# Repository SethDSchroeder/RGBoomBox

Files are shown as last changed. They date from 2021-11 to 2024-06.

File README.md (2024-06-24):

# RGBoomBox

The RGBBoomBox is a bluetooth speaker with BLINKENLIGHTS

**6/24 update** I'm reworking and completing this project now based around an Arduino MEGA board. Ideally, the first iteration will be designed as a shield for the mega which the daughter components plug into. After that, it will be revamped into a single board. All further updates to this project will be in the MEGA branch until it is semi-functional then I will merge it back into main.

**List of components used:**

* Bluetooth audio board: https://www.amazon.com/gp/product/B07W4PJ469/ref=ppx_yo_dt_b_search_asin_title?ie=UTF8&psc=1
* Audio amplifier: https://www.adafruit.com/product/1752
* RGB Matrix: https://www.adafruit.com/product/420
* Rotary encoder for volume: https://www.sparkfun.com/products/15141 and https://www.sparkfun.com/products/10597
* Matrix shield: https://www.adafruit.com/product/2601

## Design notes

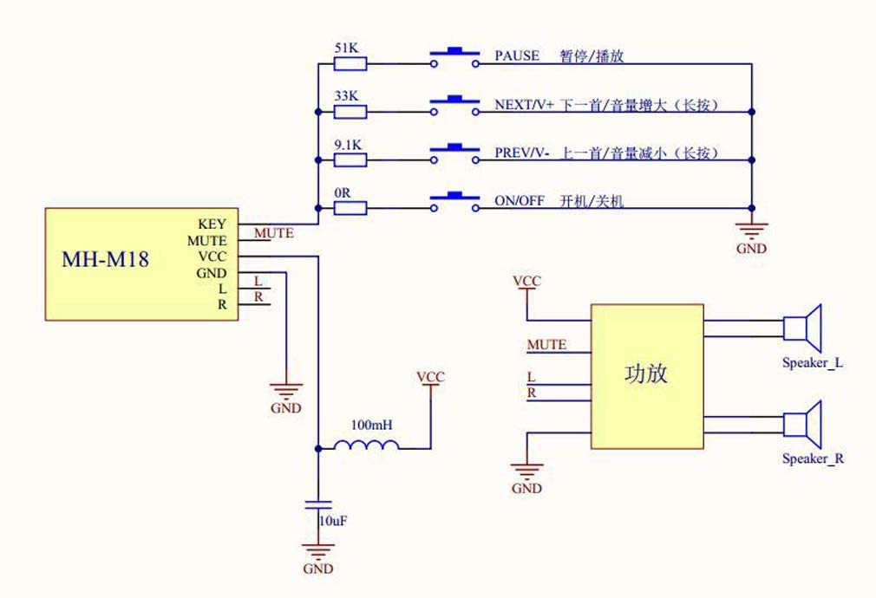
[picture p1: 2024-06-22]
bluetooth-board-layout.jpg

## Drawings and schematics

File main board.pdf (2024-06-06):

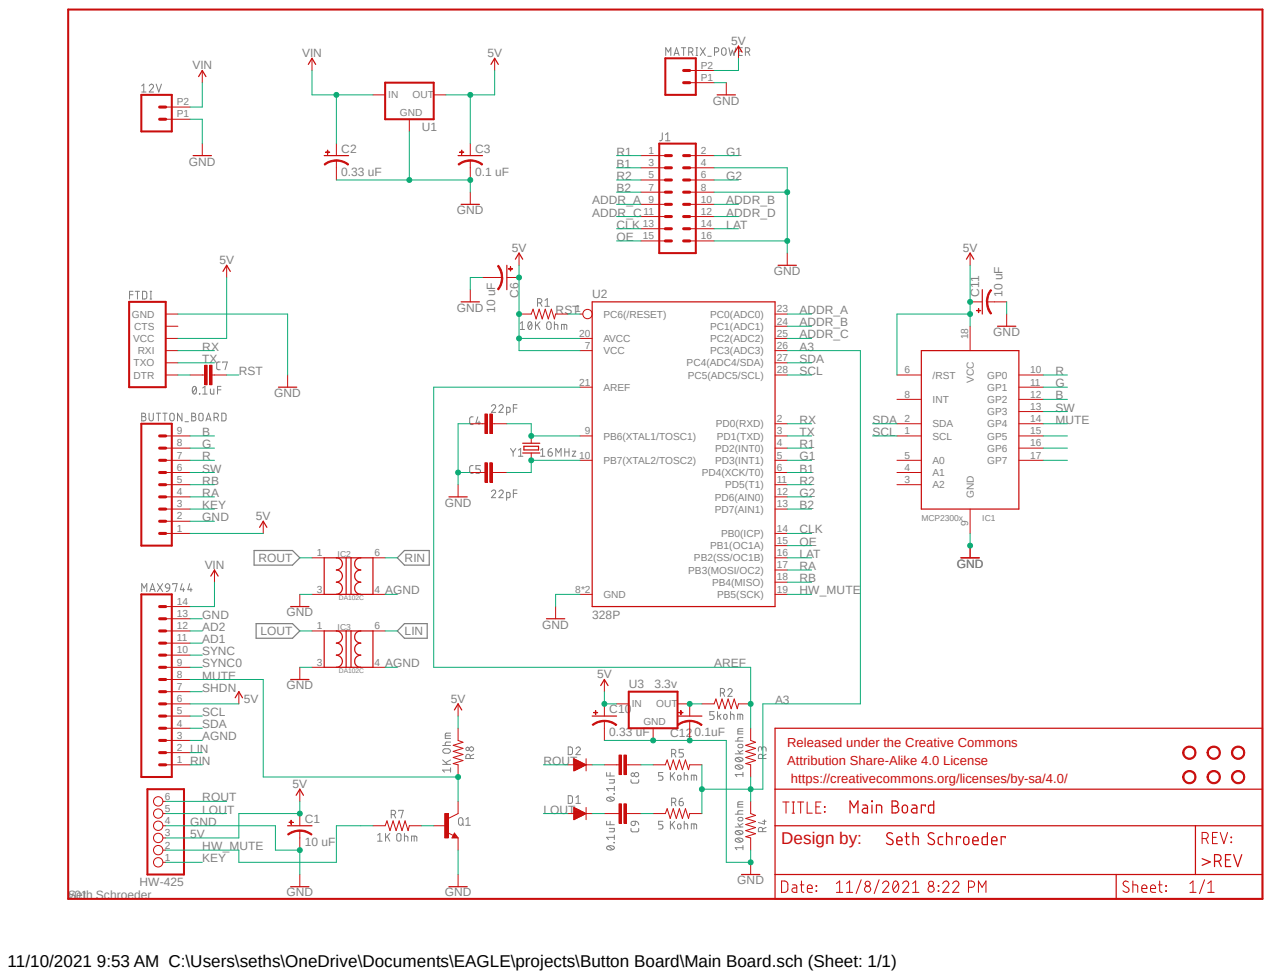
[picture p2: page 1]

Released under the Creative Commons
Attribution Share-Alike 4.0 License
https://creativecommons.org/licenses/by-sa/4.0/

11/10/2021 9:53 AM C:\Users\seths\OneDrive\Documents\EAGLE\projects\Button Board\Main Board.sch (Sheet: 1/1)

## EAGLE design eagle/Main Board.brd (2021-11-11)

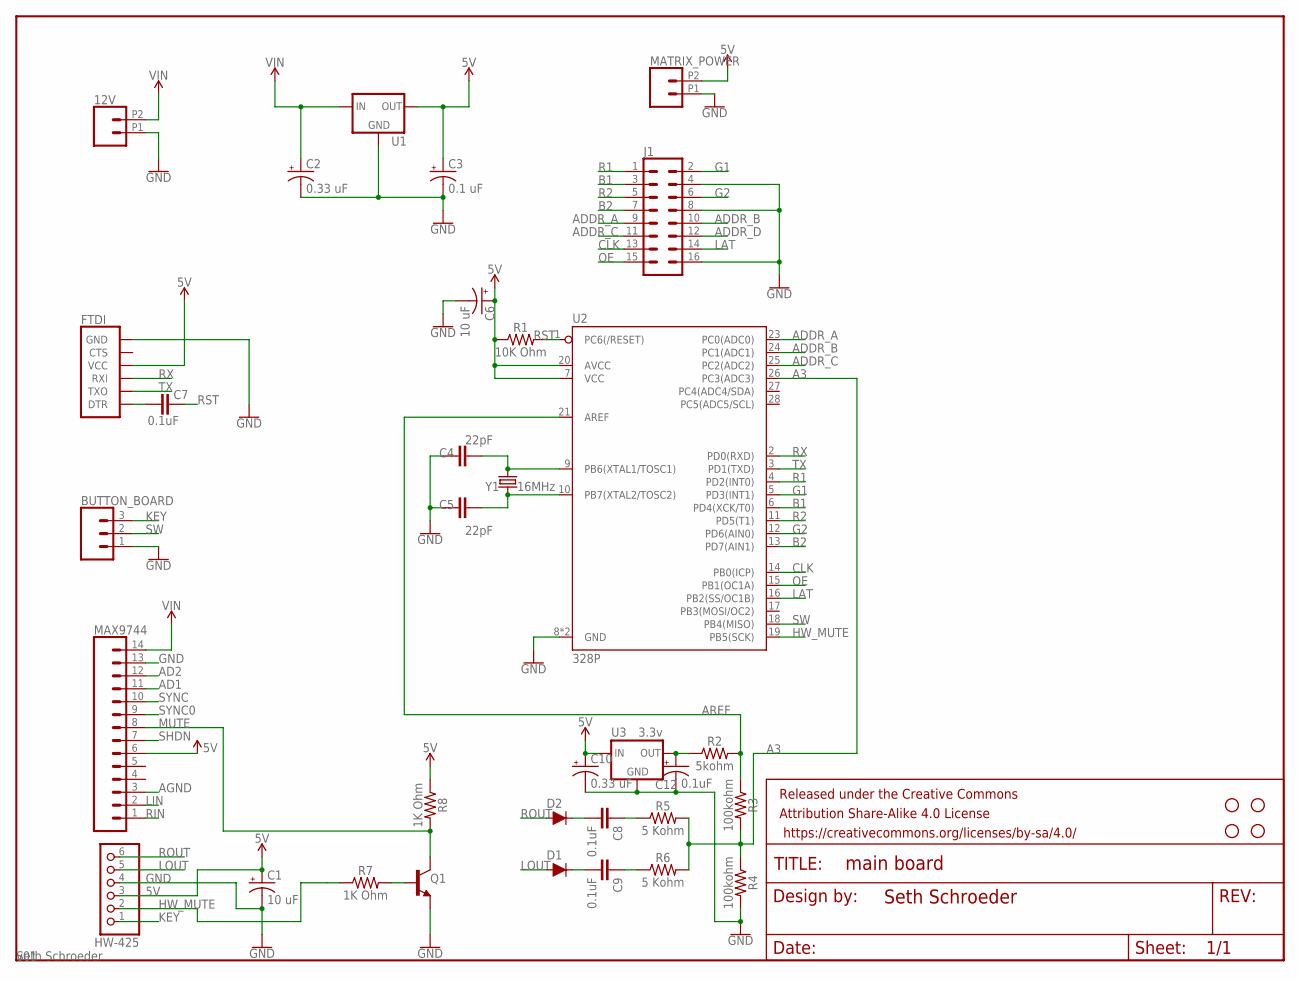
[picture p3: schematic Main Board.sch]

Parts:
12V: CONN_022.54MM_SCREWTERM; 1X02_2.54_SCREWTERM
BUTTON_BOARD: 455-1750-1-ND; 1X03
C1, C6: 10 uF; E2,5-5
C2, C10: 0.33 uF; E2,5-5
C3: 0.1 uF; E2,5-5
C4, C5: 22pF; CAP-PTH-2.54
C7, C8, C9: 0.1uF; CAP-PTH-SMALL-KIT
C12: 0.1uF; E2,5-5
D1, D2: 1A/50V/1.1V; DIODE-1N4001
FRAME1: FRAME-LETTERNO_PACKAGE; DUMMY
FTDI: 6_PIN_SERIAL_TARGETLOCK; 1X06_LOCK
H1, H2, H3, H4: STAND-OFF
HW-425: PINHD-1X6; 1X06
J1: CONN_08X2_SHROUD; 2X8-SHROUDED_LOCK
MATRIX_POWER: CONN_022.54MM_SCREWTERM; 1X02_2.54_SCREWTERM
MAX9744: CONN_14; 1X14
Q1: 200mA/40V; TO-92
R1: 10K Ohm; AXIAL-0.3
R2: 5kohm; AXIAL-0.3
R3, R4: 100kohm; AXIAL-0.3
R5, R6: 5 Kohm; AXIAL-0.3
R7, R8: 1K Ohm; AXIAL-0.3
U1: V_REG_78XXSINK; TO220-IGO
U2: 328P; DIP28
U3: 3.3v; TO-92
Y1: 16MHz; HC49US

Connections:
5V: C1.+, C3.+, C6.+, C10.+, FTDI.4 (VCC), HW-425.3, MATRIX_POWER.P2 (2), MAX9744.6, R1.P$1 (1), R8.P$1 (1), U1.OUT, U2.7 (VCC), U2.20 (AVCC), U3.3 (IN)
A3: R3.P$2 (2), R4.P$1 (1), R5.P$2 (2), R6.P$2 (2), U2.26 (PC3(ADC3))
AD1: MAX9744.11
AD2: MAX9744.12
ADDR_A: J1.9, U2.23 (PC0(ADC0))
ADDR_B: J1.10, U2.24 (PC1(ADC1))
ADDR_C: J1.11, U2.25 (PC2(ADC2))
ADDR_D: J1.12
AGND: MAX9744.3
AREF: R2.P$2 (2), R3.P$1 (1), U2.21 (AREF)
B1: J1.3, U2.6 (PD4(XCK/T0))
B2: J1.7, U2.13 (PD7(AIN1))
CLK: J1.13, U2.14 (PB0(ICP))
G1: J1.2, U2.5 (PD3(INT1))
G2: J1.6, U2.12 (PD6(AIN0))
GND: 12V.P1 (1), BUTTON_BOARD.1, C1.-, C2.-, C3.-, C4.1, C5.1, C6.-, C10.-, C12.-, FTDI.6 (GND), HW-425.4, J1.4, J1.8, J1.16, MATRIX_POWER.P1 (1), MAX9744.13, Q1.1 (E), R4.P$2 (2), U1.GND, U2.8 (GND), U2.22 (GND), U3.2 (GND)
HW_MUTE: HW-425.2, R7.P$1 (1), U2.19 (PB5(SCK))
KEY: BUTTON_BOARD.3, HW-425.1
LAT: J1.14, U2.16 (PB2(SS/OC1B))
LIN: MAX9744.2
LOUT: D1.A, HW-425.5
MUTE: MAX9744.8, Q1.3 (C), R8.P$2 (2)
unnamed: C4.2, U2.9 (PB6(XTAL1/TOSC1)), Y1.1
unnamed: C7.2, FTDI.1 (DTR)
unnamed: C5.2, U2.10 (PB7(XTAL2/TOSC2)), Y1.2
unnamed: C12.+, R2.P$1 (1), U3.1 (OUT)
unnamed: C8.1, R5.P$1 (1)
unnamed: C9.1, R6.P$1 (1)
unnamed: C8.2, D2.C
unnamed: C9.2, D1.C
unnamed: Q1.2 (B), R7.P$2 (2)
OE: J1.15, U2.15 (PB1(OC1A))
R1: J1.1, U2.4 (PD2(INT0))
R2: J1.5, U2.11 (PD5(T1))
RIN: MAX9744.1
ROUT: D2.A, HW-425.6
RST: C7.1, R1.P$2 (2), U2.1 (PC6(/RESET))
RX: FTDI.2 (RXI), U2.2 (PD0(RXD))
SHDN: MAX9744.7
SW: BUTTON_BOARD.2, U2.18 (PB4(MISO))
SYNC: MAX9744.10
SYNC0: MAX9744.9
TX: FTDI.3 (TXO), U2.3 (PD1(TXD))
VIN: 12V.P2 (2), C2.+, MAX9744.14, U1.IN

Board: 2 copper layers, 38 parts (1 on the bottom side), 35 nets, no tracks yet.

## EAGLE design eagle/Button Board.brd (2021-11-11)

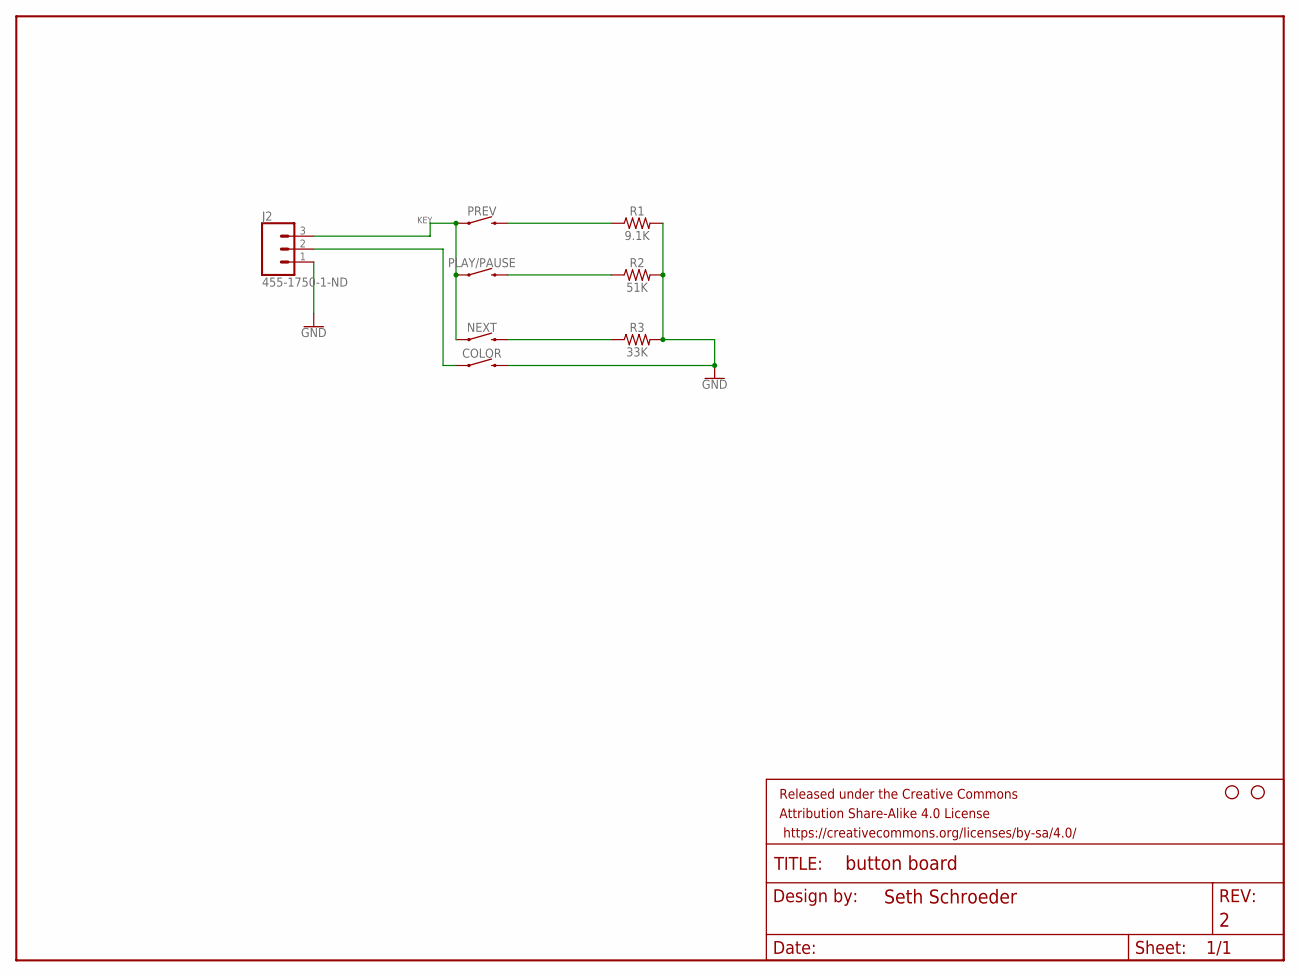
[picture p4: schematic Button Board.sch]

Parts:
COLOR: MOMENTARY-SWITCH-SPST-PTH-12MM; TACTILE_SWITCH_PTH_12MM
H1, H2: STAND-OFF
J2: 455-1750-1-ND; 1X03
ME: Seth; CREATIVE_COMMONS
NEXT: MOMENTARY-SWITCH-SPST-PTH-12MM; TACTILE_SWITCH_PTH_12MM
PLAY/PAUSE: MOMENTARY-SWITCH-SPST-PTH-12MM; TACTILE_SWITCH_PTH_12MM
PREV: MOMENTARY-SWITCH-SPST-PTH-12MM; TACTILE_SWITCH_PTH_12MM
R1: 9.1K; AXIAL-0.3
R2: 51K; AXIAL-0.3
R3: 33K; AXIAL-0.3

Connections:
GND: COLOR.3 (2), J2.1, R1.P$2 (2), R2.P$2 (2), R3.P$2 (2)
KEY: J2.3, NEXT.1, PLAY/PAUSE.1, PREV.1
unnamed: COLOR.1, J2.2
unnamed: PREV.3 (2), R1.P$1 (1)
unnamed: PLAY/PAUSE.3 (2), R2.P$1 (1)
unnamed: NEXT.3 (2), R3.P$1 (1)

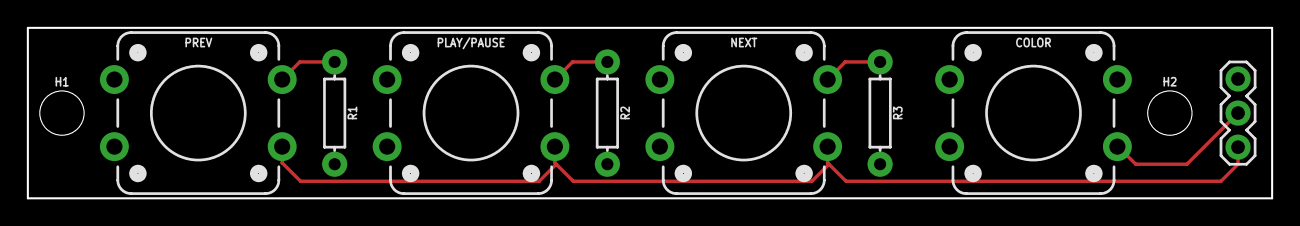
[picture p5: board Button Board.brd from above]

Board: 2 copper layers, 92.7 x 12.7 mm, 11 parts (0 on the bottom side), 6 nets.

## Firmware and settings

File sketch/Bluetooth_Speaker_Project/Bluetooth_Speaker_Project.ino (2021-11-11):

#include <PinChangeInt.h>
#include <Wire.h>
#include <Adafruit_MCP23X08.h>
#include <arduinoFFT.h>
#include <SPI.h>
#include <RGBmatrixPanel.h>

//init audio amp
// 0x4B is the default i2c address
#define MAX9744_I2CADDR 0x4B

//#define ROT_SW A1         // rotary puhbutton
// Global variables that can be changed in interrupt routines
volatile int volume = 32;                     // current "position" of rotary encoder (increments CW)
volatile boolean rotary_change = false;      // will turn true if rotary_counter has changed
volatile boolean button_pressed = false;     // will turn true if the button has been pushed
volatile boolean button_released = false;    // will turn true if the button has been released (sets button_downtime)
volatile unsigned long button_downtime = 0L; // ms the button was pushed before release
static boolean button_down = false;
static unsigned long int button_down_start, button_down_time;
boolean muted = true; //Using this boole prevents us from having to infinitely write high or low to the pin if it doesn't need to be

//Init MCP23008
Adafruit_MCP23X08 mcp;

//Init GPIO controls
#define MUTE 13  //Digital 13
#define ROT_B 12 // rotary B
#define ROT_A 11 // rotary A

//These are the values for the bars
#define SAMPLES 64 //Must be a power of 2
#define xres 32    // Total number of  columns in the display, must be <= SAMPLES/2
#define yres 16    // Total number of  rows in the display

#define NUM_LEDS (xres * yres)

#define CLK 8 // USE THIS ON ARDUINO UNO, ADAFRUIT METRO M0, etc.
//#define CLK A4 // USE THIS ON METRO M4 (not M0)
//#define CLK 11 // USE THIS ON ARDUINO MEGA
#define OE 9
#define LAT 10
#define A A0
#define B A1
#define C A2

//Init the matrix panel
RGBmatrixPanel matrix(A, B, C, CLK, LAT, OE, false);

byte yvalue;
byte displaycolumn, displayvalue;
int peaks[xres];
byte state = HIGH;        // the current reading from the input pin
byte previousState = LOW; // the previous reading from the input pin
byte displaycolor = 0;

//Arrays for samplig
double vReal[SAMPLES];
double vImag[SAMPLES];
byte data_avgs[xres];
arduinoFFT FFT = arduinoFFT(); // FFT object

unsigned long lastDebounceTime = 0; // the last time the output pin was toggled
unsigned long debounceDelay = 100;  // the debounce time; increase if the output flickers

// EQ filter to attenuates bass and improves treble
// Useful on PC sound card which usually has many bass and poor high frequency
bool EQ_ON = true; // set to false to disable eq
byte eq[32] = {5, 10, 30, 70, 75, 80, 85, 95,
               100, 100, 100, 100, 100, 100, 100, 100,
               100, 100, 100, 100, 100, 100, 100, 100,
               115, 125, 140, 160, 185, 200, 225, 255};

void setup()
{

  //Initialize audio amplifer
  Serial.begin(9600);
  Serial.println("MAX9744 demo with volume modulated by rotary encoder.");
  Wire.begin();

  if (!setvolume(volume))
  {
    Serial.println("Failed to set volume, MAX9744 not found!");
    while (1)
      ;
  }

  //Init mcp
  /* if (!mcp.begin_I2C())
  {
    Serial.println("Cannot address mcp chip.");
    while (1)
      ;
  } */

  //Init matrix
  matrix.begin();
  ADCSRA = 0b11100101; // set ADC to free running mode and set pre-scalar to 32 (0xe5)
  ADMUX = 0b00000011;  // use pin A4 and internal voltage reference

  //Init GPIO
  //Rotary encoder
  pinMode(ROT_B, INPUT);
  digitalWrite(ROT_B, HIGH); // turn on weak pullup
  pinMode(ROT_A, INPUT);
  digitalWrite(ROT_A, HIGH); // turn on weak pullup
  //pinMode(ROT_SW, INPUT);
  //Interrupts for the rotary encoder
  //attachInterrupt(digitalPinToInterrupt(3), rotaryIRQ, CHANGE);
  PCintPort::attachInterrupt(ROT_A, &rotaryIRQ, CHANGE);
  //muting
  pinMode(MUTE, INPUT);
}


void rotaryIRQ()
{
  static unsigned char rotary_state = 0; // current and previous encoder states

  rotary_state <<= 2;                                               // remember previous state
  rotary_state |= (digitalRead(ROT_A) | (digitalRead(ROT_B) << 1)); // mask in current state
  rotary_state &= 0x0F;                                             // zero upper nybble

  Serial.println(rotary_state, HEX);

  if (rotary_state == 0x06) // from 10 to 01, increment counter. Also try 0x06 if unreliable
  {
    volume++;
    rotary_change = true;
  }
  else if (rotary_state == 0x0C) // from 00 to 11, decrement counter. Also try 0x0C if unreliable
  {
    volume--;
    rotary_change = true;
  }
}

boolean setvolume(int8_t v)
{
  Serial.print("Setting volume to ");
  Serial.println(v);
  Wire.beginTransmission(MAX9744_I2CADDR);
  Wire.write(v);
  if (Wire.endTransmission() == 0)
    return true;
  else
    return false;
}

void loop()
{
  if (rotary_change)
  {
    volume = constrain(volume, 0, 63);
    setvolume(volume);
    rotary_change = false;
  }
  if (!digitalRead(MUTE))
  { //If the hw board IS playing
    muted = false;
  }
  if (digitalRead(MUTE))
  { //If hw board is NOT playing
    muted = true;
  }

  // ++ Sampling
  for (int i = 0; i < SAMPLES; i++)
  {
    while (!(ADCSRA & 0x10))
      ;                    // wait for ADC to complete current conversion ie ADIF bit set
    ADCSRA = 0b11110101;   // clear ADIF bit so that ADC can do next operation (0xf5)
    int value = ADC - 512; // Read from ADC and subtract DC offset caused value
    vReal[i] = value / 8;  // Copy to bins after compressing
    vImag[i] = 0;
  }

  FFT.Windowing(vReal, SAMPLES, FFT_WIN_TYP_HAMMING, FFT_FORWARD);
  FFT.Compute(vReal, vImag, SAMPLES, FFT_FORWARD);
  FFT.ComplexToMagnitude(vReal, vImag, SAMPLES);

  // -- FFT
  // ++ re-arrange FFT result to match with no. of columns on display (xres)
  int step = (SAMPLES / 2) / xres;
  int c = 0;
  for (int i = 0; i < (SAMPLES / 2); i += step)
  { //This just loops through 32
    data_avgs[c] = 0;
    for (int k = 0; k < step; k++)
    {
      data_avgs[c] = data_avgs[c] + vReal[i + k];
    }
    data_avgs[c] = data_avgs[c] / step;
    c++;
  }

  // ++ send to display according measured value
  for (int i = 0; i < xres; i++)
  { //again looping through 32
    if (EQ_ON)
      data_avgs[i] = data_avgs[i] * (float)(eq[i]) / 100; //apply eq filter
    data_avgs[i] = constrain(data_avgs[i], 0, 50);        // set max & min values for buckets to 0-80
    data_avgs[i] = map(data_avgs[i], 0, 50, 0, yres);     // remap averaged values to yres 0-8
    yvalue = data_avgs[i];
    peaks[i] = peaks[i] - 1; // decay by one light
    if (yvalue > peaks[i])
      peaks[i] = yvalue; //save peak if > previuos peak
    yvalue = peaks[i];
    displaycolumn = i;
    displayvalue = yvalue;
    matrix.drawLine(displaycolumn, 0, displaycolumn, 15, matrix.Color333(0, 0, 0)); //Clear the column first before drawing it again
    matrix.drawLine(displaycolumn, 15 - displayvalue, displaycolumn, 15, matrix.Color333(random(0, 8), random(0, 8), random(0, 8))); //Draw the column
  }
}

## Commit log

2021-11-11 Added eagle files
    [Button Board.brd, Button Board.sch, Main Board.brd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]
2024-06-06 Added main board PDF
2024-06-22 added bluetooth board button schematic for reference
2024-06-24 Changed directory structure to satisfy arduino uno

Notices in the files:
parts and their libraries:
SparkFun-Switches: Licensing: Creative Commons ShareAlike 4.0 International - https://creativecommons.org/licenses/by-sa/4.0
